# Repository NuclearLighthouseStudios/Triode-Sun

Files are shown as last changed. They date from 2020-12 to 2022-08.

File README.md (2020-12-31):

# Triode Sun Tube Preamp

These are the KiCAD schematics and board layout filed for my Triode Sun Tube Preamp pedal.  
If you just want the Gerber files or a PDF of the schematic check out the releases tab for downloads.

This PCB should be easily manufacturable with most online PCB houses by just uploading the gerber files.

This board is designed to be used with my Switchboard Pedal IO PCB which you can find [here](https://github.com/NuclearLighthouseStudios/Switchboard).

## BOM

| Reference | Quantity | Value  | Description |
| :--- | ---: | -----: | :--- |
| C2 C4 | 2 | 470n | WIMA MKS2 50V |
| C1 C3 C5 | 3 | 100n | WIMA MKS2 63V |
| C6 | 1 | 1µ | WIMA MKS2 50V |
| J1 | 1 | | Pin Header, 6 pins, 2.54mm spacing |
| J2 | 1 | | DC Barrel Jack with internal switch |
| Q1 Q2 | 2 | BC547B | 0.1A Ic, 45V Vce, Small Signal NPN Transistor, TO-92 |
| R1 R2 R5 R9 R10 | 5 | 1M | Metal film resistor 1%, DIN 0207 |
| R3 R11 | 2 | 10k | Metal film resistor 1%, DIN 0207 |
| R4 R12 | 2 | 39k | Metal film resistor 1%, DIN 0207 |
| R6 R7 | 2 | 390K | Metal film resistor 1%, DIN 0207 |
| R8 | 1 | 100K | Metal film resistor 1%, DIN 0207 |
| RV1 RV2 | 2 | 100k | Alps RK09K1130C94 Potentiometer |
| U1 | 1 | ECC82  | ECC82 / 17AU7 in noval print socket |

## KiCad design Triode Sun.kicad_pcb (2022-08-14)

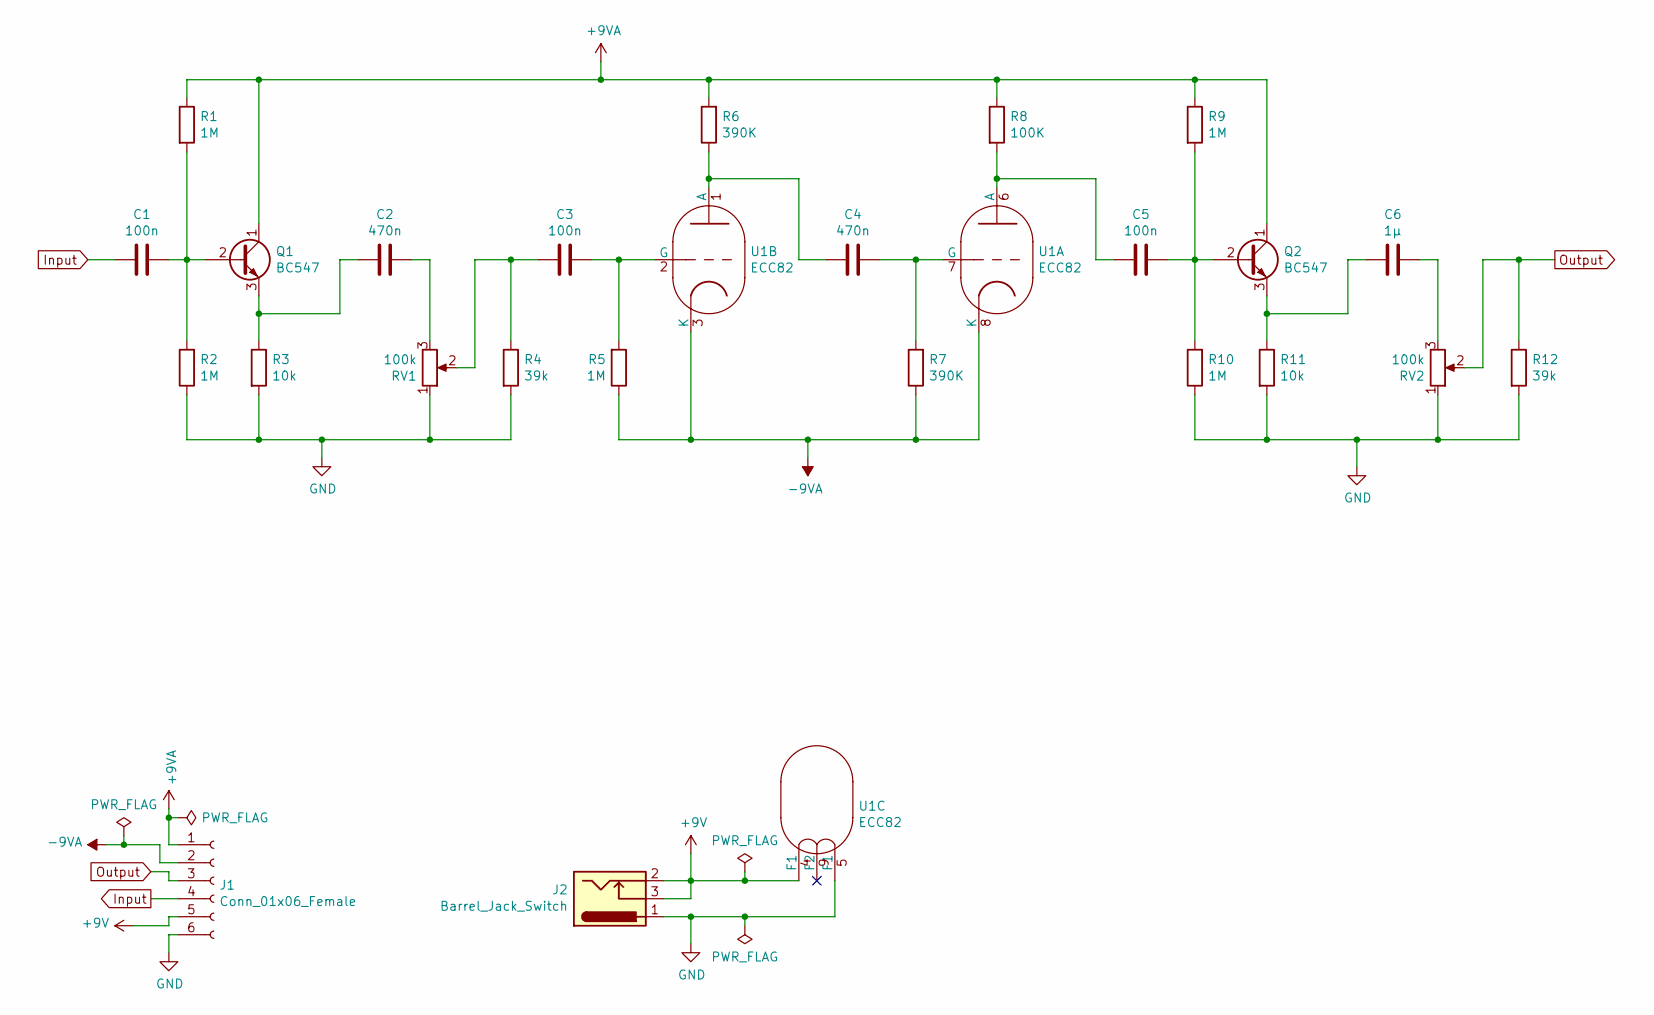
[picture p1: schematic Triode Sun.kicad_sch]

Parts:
C1, C3, C5: 100n; C_Rect_L7.2mm_W2.5mm_P5.00mm_FKS2_FKP2_MKS2_MKP2
C2, C4: 470n; C_Rect_L7.2mm_W3.5mm_P5.00mm_FKS2_FKP2_MKS2_MKP2
C6: 1µ; C_Rect_L7.2mm_W4.5mm_P5.00mm_FKS2_FKP2_MKS2_MKP2
J1: Conn_01x06_Female; PinHeader_1x06_P2.54mm_Vertical
J2: Barrel_Jack_Switch; BarrelJack_Horizontal_Short
Q1, Q2: BC547; TO-92_Wide
R1, R2, R5, R9, R10: 1M; R_Axial_DIN0207_L6.3mm_D2.5mm_P2.54mm_Vertical
R3, R11: 10k; R_Axial_DIN0207_L6.3mm_D2.5mm_P2.54mm_Vertical
R4, R12: 39k; R_Axial_DIN0207_L6.3mm_D2.5mm_P2.54mm_Vertical
R6, R7: 390K; R_Axial_DIN0207_L6.3mm_D2.5mm_P2.54mm_Vertical
R8: 100K; R_Axial_DIN0207_L6.3mm_D2.5mm_P2.54mm_Vertical
RV1, RV2: 100k; Potentiometer_Alps_RK09K_Single_Vertical
U1: ECC82; SOCKET-NOVAL

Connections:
+9V: J1.5, J2.2, J2.3, U1.4 (F1)
+9VA: J1.1, Q1.1 (C), Q2.1 (C), R1.1, R6.2, R8.1, R9.1
-9VA: J1.2, R5.1, R7.1, U1.3 (K), U1.8 (K)
GND: J1.6, J2.1, R2.1, R3.2, R4.2, R10.1, R11.2, R12.2, RV1.1, RV2.1, U1.5 (F1)
Input: C1.2, J1.4
unnamed: C1.1, Q1.2 (B), R1.2, R2.2
unnamed: C2.1, RV1.3
unnamed: C2.2, Q1.3 (E), R3.1
unnamed: C3.1, R5.2, U1.2 (G)
unnamed: C3.2, R4.1, RV1.2
unnamed: C4.1, R7.2, U1.7 (G)
unnamed: C4.2, R6.1, U1.1 (A)
unnamed: C5.1, Q2.2 (B), R9.2, R10.2
unnamed: C5.2, R8.2, U1.6 (A)
unnamed: C6.1, RV2.3
unnamed: C6.2, Q2.3 (E), R11.1
Output: J1.3, R12.1, RV2.2

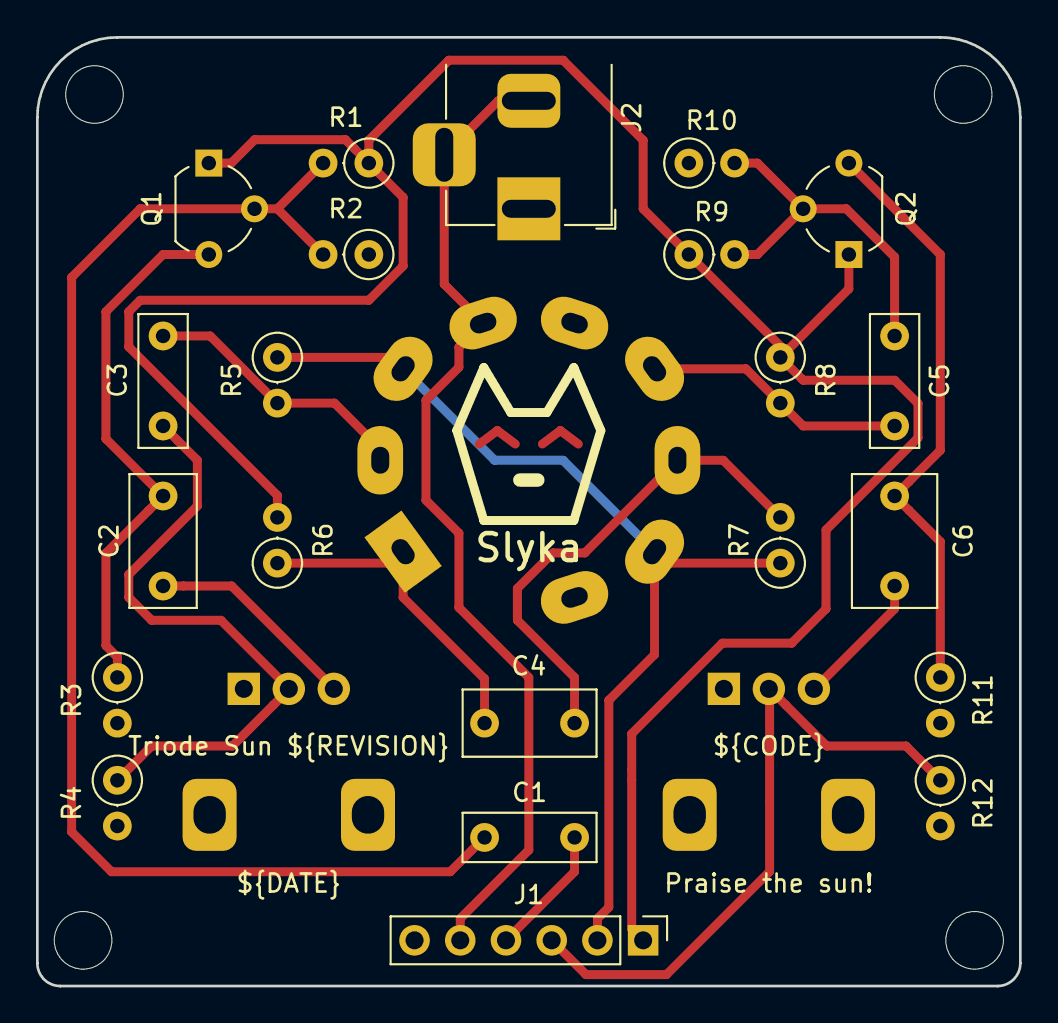
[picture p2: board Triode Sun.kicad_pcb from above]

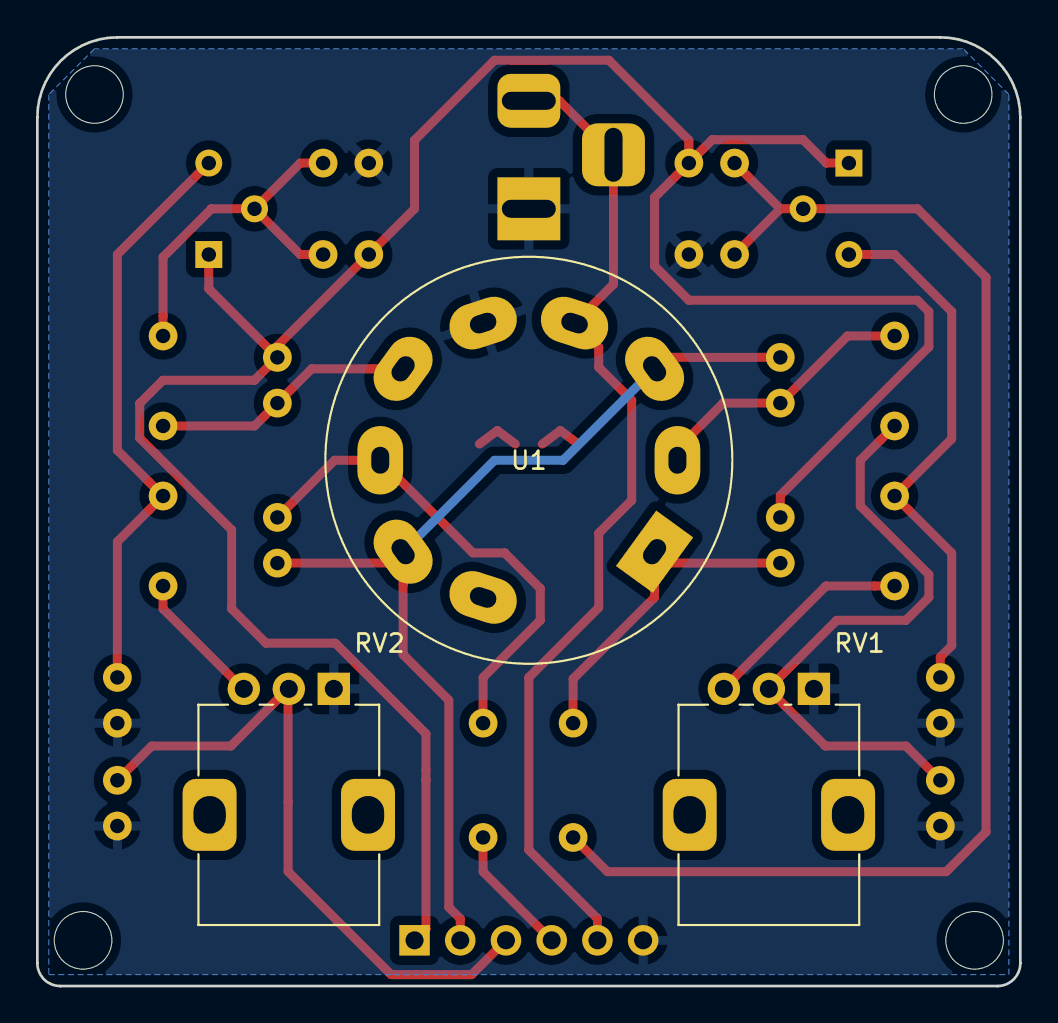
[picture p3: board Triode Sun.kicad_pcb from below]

Board: 2 copper layers, 54.6 x 52.7 mm, 25 parts (3 on the bottom side), 17 nets.

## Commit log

2020-09-28 Public release! Yay!
    [Triode Sun.kicad_pcb, Triode Sun.sch]
2020-12-30 Add readme with BOM! Yay!
2020-12-31 Fix cap voltages
2022-01-21 Migrate to KiCAD 6
    [Triode Sun.kicad_pcb, Triode Sun.kicad_sch, Triode Sun.sch]
2022-08-14 Update footprints and libraries
    [Triode Sun.kicad_pcb, Triode Sun.kicad_sch]
2022-08-14 Fix DRC errors
    [Triode Sun.kicad_pcb]

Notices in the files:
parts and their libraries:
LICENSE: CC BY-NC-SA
